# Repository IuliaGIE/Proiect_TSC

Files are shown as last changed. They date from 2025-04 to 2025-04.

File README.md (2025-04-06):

# DeskAssistant v15 – ESP32-C6 Smart E-Ink Device

## 🔧 Diagrama bloc

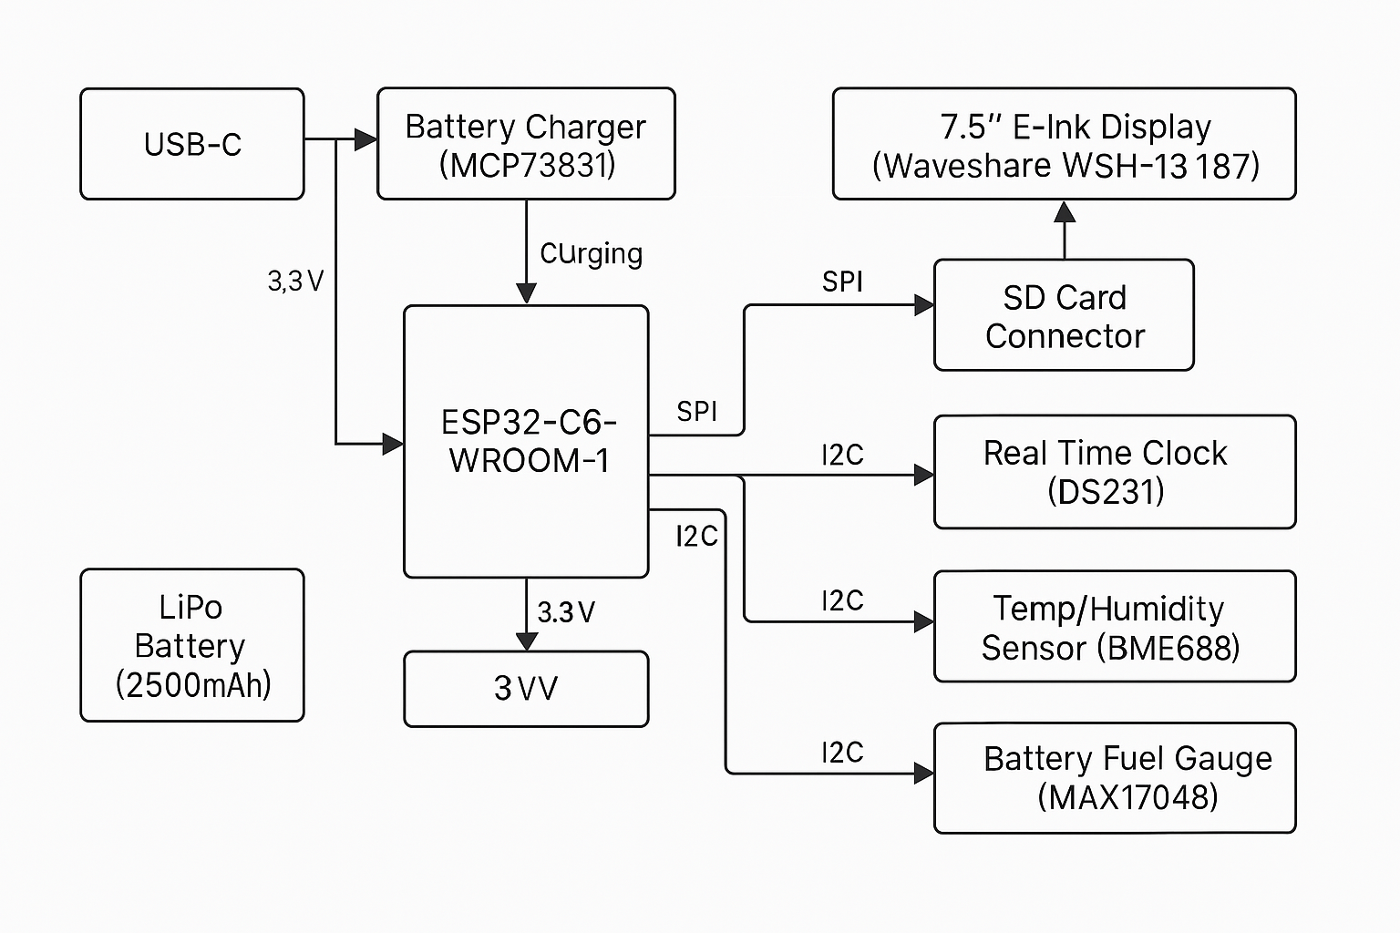
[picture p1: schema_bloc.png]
Diagrama Bloc


---

# Bill of Materials
| Componenta | Link | Datasheet
| --- | --- |---|
|ESP32_WROVER_BME680_BME680|https://www.snapeda.com/parts/BME680/Bosch/view-part/?welcome=home|https://www.snapeda.com/parts/BME680/Bosch%20Sensortec/datasheet/|
|ESP32_WROVER_EAGLE-LTSPICE_CC0402|https://componentsearchengine.com/Datasheets/2/CC0402MRX5R5BB106.pdf|https://componentsearchengine.com/part-view/CC0402MRX5R5BB106/YAGEO|
|ESP32_WROVER_SPARKFUN-DISCRETESEMI_MOSFET_PCH-DMG2305UX-7|https://componentsearchengine.com/part-view/DMG2305UX-7/Diodes%20Incorporated|https://www.diodes.com//assets/Datasheets/DMG2305UX.pdf|
|ESP32C6_VARISTORCN1812|https://www.mouser.co.uk/ProductDetail/EPCOS-TDK/B72520T0350K062?qs=dEfas%2FXlABIszF52uu7vrg%3D%3D|https://www.tdk-electronics.tdk.com/inf/75/db/CTVS_14/Surge_protection_series.pdf|
|FH34SRJ-24S-0.5SH_99_|https://componentsearchengine.com/part-view/XC6220A331MR-G/Torex|https://product.torexsemi.com/system/files/series/xc6220.pdf|
|MAX17048G+T10|https://www.snapeda.com/parts/MAX17048G+T10/Analog+Devices/view-part/?ref=eda|https://www.snapeda.com/parts/MAX17048G+T10/Analog%20Devices/datasheet/|
|MBR0530|https://ro.mouser.com/ProductDetail/KYOCERA-AVX/SD0805S020S1R0?qs=jCA%252BPfw4LHbpkAoSnwrdjw%3D%3D|https://ro.mouser.com/datasheet/2/40/schottky-3165252.pdf|
|PGB1010603MR|https://www.snapeda.com/parts/PGB1010603MR/Littelfuse/view-part/?ref=eda|https://www.snapeda.com/parts/PGB1010603MR/Littelfuse%20Inc./datasheet/|
|RCL_CPOL-EUCT3528|https://ro.mouser.com/ProductDetail/Vishay-Sprague/TR3B106K025C1300?qs=jCGqFXxTmLdffnuDkXzk1g%3D%3D|https://www.vishay.com/docs/40080/tr3.pdf|
|SAMACSYS_PARTS_USB4110-GF-A|https://componentsearchengine.com/part-view/USB4110-GF-A/GCT%20(GLOBAL%20CONNECTOR%20TECHNOLOGY)|https://gct.co/files/drawings/usb4110.pdf|
|SI1308EDL-T1-GE3|https://componentsearchengine.com/part-view/SI1308EDL-T1-GE3/Vishay|https://componentsearchengine.com/Datasheets/1/SI1308EDL-T1-GE3.pdf|
|SJ|https://grabcad.com/library/solder-jumpers-1||
|USBLC6-2SC6Y|https://www.snapeda.com/parts/USBLC6-2SC6Y/STMicroelectronics/view-part/?ref=eda|https://www.snapeda.com/parts/USBLC6-2SC6Y/STMicroelectronics/datasheet/|
|W25Q512JVEIQ|https://www.snapeda.com/parts/W25Q512JVEIQ/Winbond+Electronics/view-part/?ref=eda|https://www.snapeda.com/parts/W25Q512JVEIQ/Winbond%20Electronics/datasheet/|
|XC6220A331MR-G|https://componentsearchengine.com/part-view/XC6220A331MR-G/Torex|https://product.torexsemi.com/system/files/series/xc6220.pdf|
| ESP32_WROVER_EAGLE-LTSPICE_RR0402  | https://www.snapeda.com/parts/RC0402FR-07226RL/Yageo/view-part/ |https://www.snapeda.com/parts/RC0402FR-07226RL/Yageo/datasheet/
| QWIIC_CONNECTORJS-1MM | https://www.snapeda.com/parts/PRT-14417/SparkFun/view-part/ |https://www.snapeda.com/parts/PRT-14417/SparkFun%20Electronics/datasheet/
|BUTTON_CUSYOMV1|https://industry.panasonic.com/global/en/downloads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|https://industry.panasonic.com/global/en/downloads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
|ESP32_WROVER_EAGLE-LTSPICE_CC0402|https://componentsearchengine.com/part-view/CC0402MRX5R5BB106/YAGEO|https://componentsearchengine.com/Datasheets/2/CC0402MRX5R5BB106.pdf
|CPH3225A|https://www.snapeda.com/parts/CPH3225A/Seiko+Instruments/view-part/?ref=eda|https://www.snapeda.com/parts/CPH3225A/Seiko%20Instruments/datasheet/|
|ADAFRUIT_LEDCHIP-LED0603|https://www.snapeda.com/parts/KP-1608SURCK/Kingbright/view-part/?ref=search&t=LED%200603|https://www.snapeda.com/parts/KP-1608SURCK/Kingbright/datasheet/
|112A-TAAR-R03_ATTEND|https://store.comet.bg/en/Catalogue/Product/43497/|https://store.comet.bg/en/Catalogue/Product/43497/|
|744043680IND_4828-WE-TPC_WRE|https://www.digikey.sg/en/models/1638515|https://www.we-online.com/components/products/datasheet/744043680.pdf
|BD5229G-TR|https://componentsearchengine.com/part-view/BD5229G-TR/ROHM%20Semiconductor|https://datasheet.datasheetarchive.com/originals/distributors/Datasheets_SAMA/f2b9741ef86007909f138d561a359946.pdf|
|CPH3225A|https://www.snapeda.com/parts/CPH3225A/Seiko+Instruments/view-part/?ref=eda|https://www.snapeda.com/parts/CPH3225A/Seiko%20Instruments/datasheet/|
|DS3231SN|https://www.snapeda.com/parts/DS3231SN%23/Analog+Devices/view-part/?ref=eda|https://www.snapeda.com/parts/DS3231SN%23/Analog%20Devices/datasheet/|
|ESP32-C6-WROOM-1-N8|https://www.snapeda.com/parts/ESP32-C6-WROOM-1-N8/Espressif+Systems/view-part/?ref=eda|https://www.snapeda.com/parts/ESP32-C6-WROOM-1-N8/Espressif%20Systems/datasheet/
|MCP73831|https://www.digikey.com/en/models/1874108|https://ww1.microchip.com/downloads/aemDocuments/documents/APID/ProductDocuments/DataSheets/MCP73831-Family-Data-Sheet-DS20001984H.pdf|

---

## 🧠 Funcționalitate Hardware

DeskAssistant v15 este un dispozitiv portabil cu ecran E-Ink, destinat afișării de informații de mediu, oră și nivel baterie. Este alimentat fie prin USB-C, fie dintr-o baterie LiPo de 2500 mAh.

### Flux de alimentare:
- Portul USB-C oferă 5V către MCP73831, care încarcă bateria LiPo.
- Tensiunea de 3.7V de la baterie este convertită de un LDO în 3.3V, alimentând toate componentele.
- Monitorizarea bateriei este realizată cu MAX17048.

### Senzori și afișaj:
- Temperatura, umiditatea, presiunea și compușii volatili (VOC) sunt măsurați cu senzorul BME688 prin magistrala I2C.
- RTC-ul DS3231 furnizează ora exactă, tot prin I2C.
- Afișajul E-Ink de 7.5 inch este conectat prin SPI și oferă un consum redus de energie.
- Datele pot fi salvate pe un card microSD (SPI).
- Trei butoane conectate pe GPIO sunt utilizate pentru controlul interfeței.

### Calcul estimativ consum:
- ESP32-C6: ~20mA în idle, ~200mA în Wi-Fi TX
- E-Ink: consum doar în actualizare (~26mA)
- BME688: ~2.1mA în mod activ
- RTC: ~1.5μA
- MAX17048: ~50μA
- Autonomie estimată: ~30-40 ore în regim normal, cu Wi-Fi ocazional

---

## 📌 Maparea pinilor ESP32-C6

| Componentă | Pin ESP32-C6 | Interfață | Motivare |
|---|---|---|---|
| E-Ink Display | GPIO4 (MOSI), GPIO5 (MISO), GPIO6 (SCK), GPIO7 (CS), GPIO8 (DC), GPIO9 (RST), GPIO10 (BUSY) | SPI | Control complet al ecranului |
| SD Card | GPIO11 (CS2) | SPI (partajat) | Acces la stocare externă |
| BME688 | GPIO18 (SDA), GPIO19 (SCL) | I2C | Măsurători ambientale |
| MAX17048 | GPIO18 (SDA), GPIO19 (SCL) | I2C | Nivel baterie |
| DS3231 RTC | GPIO18 (SDA), GPIO19 (SCL) | I2C | Ceas exact |
| Butoane | GPIO21, GPIO22, GPIO23 | GPIO IN | Control manual |
| USB-C | GPIO20 (USB D+), GPIO21 (USB D-) | USB-Serial | Flash & debug |
| LED status | GPIO2 | GPIO OUT | Indicație vizuală |

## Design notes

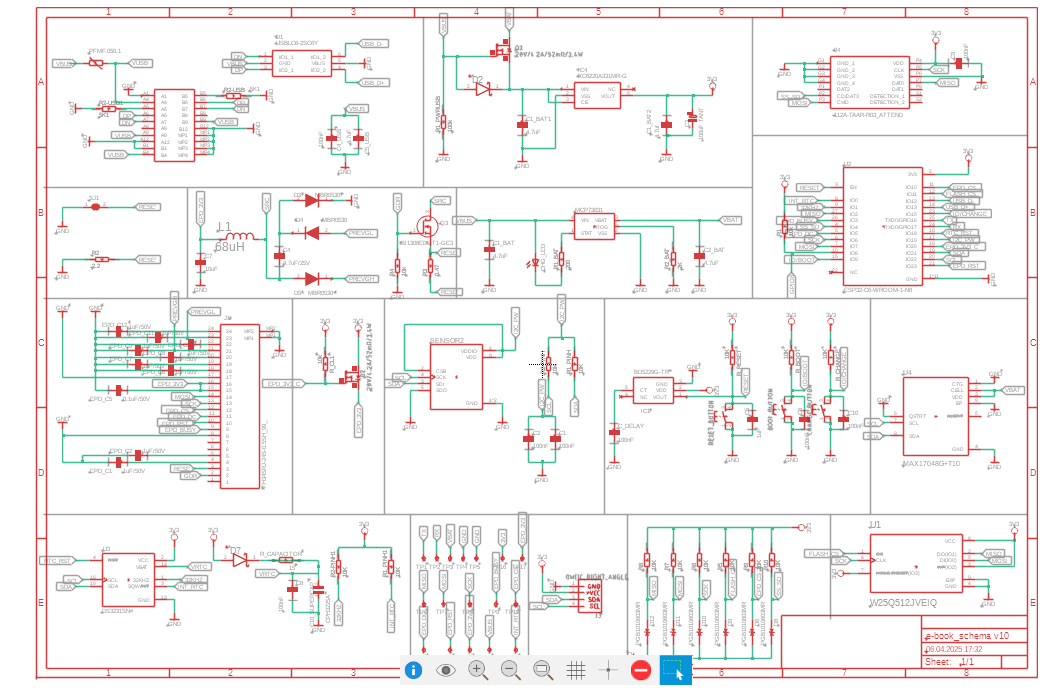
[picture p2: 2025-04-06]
Images/schema.png

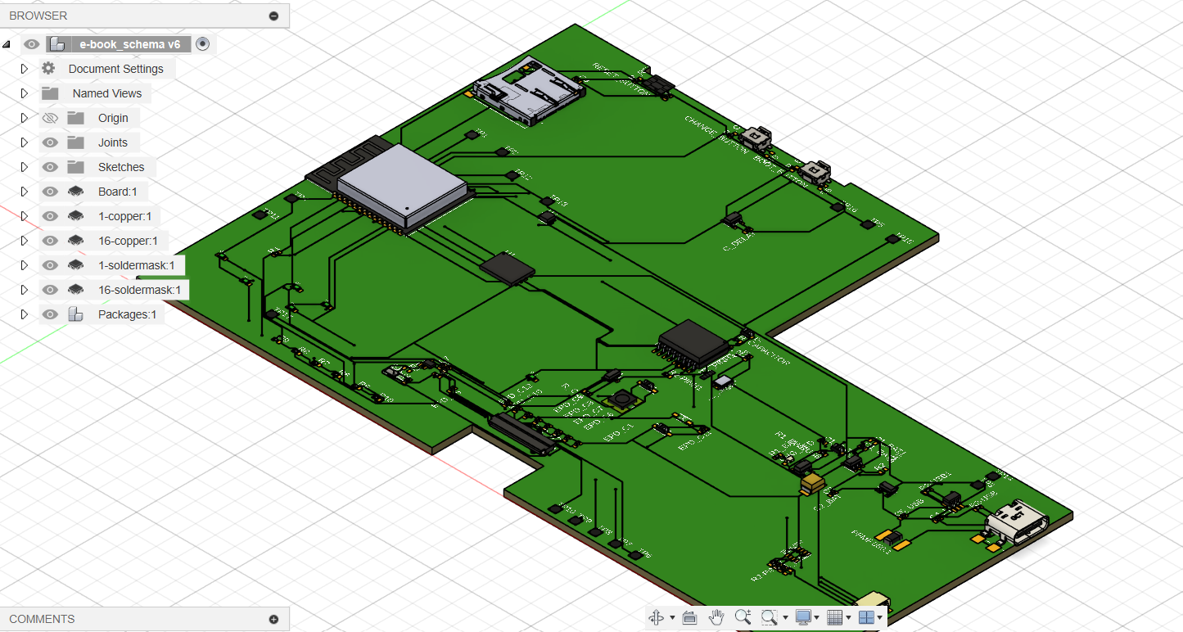
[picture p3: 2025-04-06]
Images/placuta.png

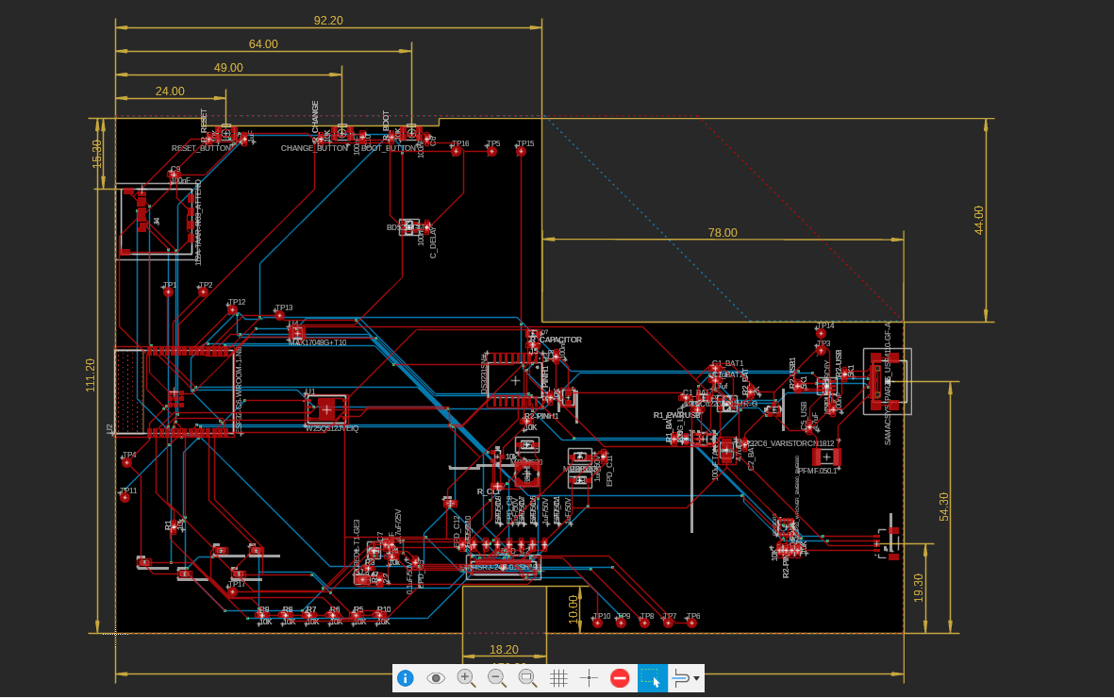
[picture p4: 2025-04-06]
Images/pcb.png

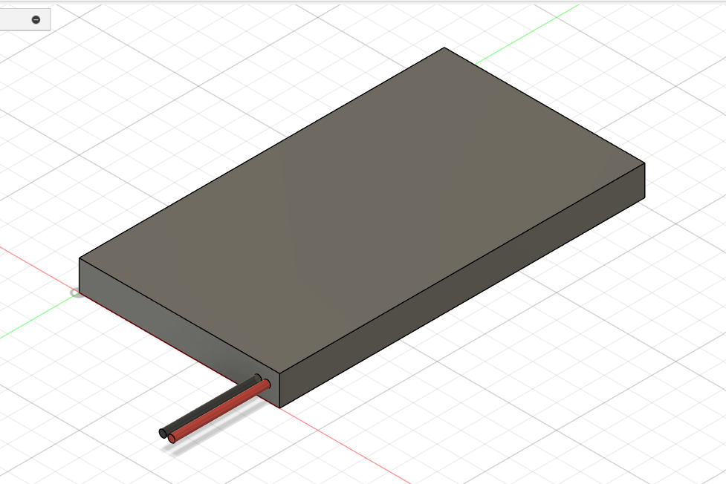
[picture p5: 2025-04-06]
Images/baterie.png

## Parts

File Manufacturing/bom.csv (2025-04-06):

Qty | Value | Device | Package | Parts | Description | ARROW_PART_NUMBER | ARROW_PRICE-STOCK | AVAILABILITY | CENTROID_NOT_SPECIFIED | CHECK_PRICES | COPYRIGHT | DATASHEET | DESCRIPTION | DIGIKEY_DESCRIPTION | DIGIKEY_PART_NUMBER | HEIGHT | LEAD_FREE | MANUFACTURER_NAME | MANUFACTURER_PART_NUMBER | MF | MFR_NAME | MOUSER_PART_NUMBER | MOUSER_PRICE-STOCK | MOUSER_TESTING_PART_NUMBER | MOUSER_TESTING_PRICE-STOCK | MP | MPN | PACKAGE | POPULARITY | PREFIX | PRICE | PROD_ID | PURCHASE-URL | ROHS | SNAPEDA_LINK | SPICEMODEL | SPICEPREFIX | TEMPERATURE_RANGE_HIGH | TEMPERATURE_RANGE_LOW | TP_SIGNAL_NAME | VALUE
1 |  | ADAFRUIT_LEDCHIP-LED0603 | ADAFRUIT_CHIP-LED0603 | CHG_LED | LED
1 |  | SJ | SJ | SJ1 | SMD solder JUMPER |  |  |  |  |  |  |  |  |  |  |  |  |  |  |  |  |  |  |  |  |  |  |  | 3
1 | 0.1uF/50V | EAGLE-LTSPICE_CC0402 | EAGLE-LTSPICE_C0402 | EPD_C5 | CAPACITOR, European symbol |  |  |  |  |  |  |  |  |  |  |  |  |  |  |  |  |  |  |  |  |  |  |  |  |  |  |  |  |  |  | NONE | C
1 | 0.47 | ESP32_WROVER_EAGLE-LTSPICE_RR0402 | ESP32_WROVER_EAGLE-LTSPICE_R0402 | R3 | RESISTOR, European symbol |  |  |  |  |  |  |  |  |  |  |  |  |  |  |  |  |  |  |  |  |  |  |  |  |  |  |  |  |  |  | NONE | R
1 | 100k | ESP32_WROVER_EAGLE-LTSPICE_RR0402 | ESP32_WROVER_EAGLE-LTSPICE_R0402 | R1_PWRUSB | RESISTOR, European symbol |  |  |  |  |  |  |  |  |  |  |  |  |  |  |  |  |  |  |  |  |  |  |  |  |  |  |  |  |  |  | NONE | R
8 | 100nF | EAGLE-LTSPICE_CC0402 | EAGLE-LTSPICE_C0402 | C1, C2, C4_USB, C6, C8, C9, C10, C_DELAY | CAPACITOR, European symbol |  |  |  |  |  |  |  |  |  |  |  |  |  |  |  |  |  |  |  |  |  |  |  |  |  |  |  |  |  |  | NONE | C
1 | 100uF TANT | RCL_CPOL-EUCT3528 | RCL_CT3528 | C3 | POLARIZED CAPACITOR, European symbol |  |  |  |  |  |  |  |  |  |  |  |  |  |  |  |  |  |  |  |  |  |  |  | 0 |  |  |  |  |  |  |  | C
13 | 10K | ESP32_WROVER_EAGLE-LTSPICE_RR0402 | ESP32_WROVER_EAGLE-LTSPICE_R0402 | R1_PINH, R1_PINH1, R2-PINH, R2-PINH1, R5, R6, R7, R8, R9, R10, R_BOOT, R_CHANGE, R_RESET | RESISTOR, European symbol |  |  |  |  |  |  |  |  |  |  |  |  |  |  |  |  |  |  |  |  |  |  |  |  |  |  |  |  |  |  | NONE | R
3 | 10k | ESP32_WROVER_EAGLE-LTSPICE_RR0402 | ESP32_WROVER_EAGLE-LTSPICE_R0402 | R1, R4, R_CL1 | RESISTOR, European symbol |  |  |  |  |  |  |  |  |  |  |  |  |  |  |  |  |  |  |  |  |  |  |  |  |  |  |  |  |  |  | NONE | R
1 | 10uF | EAGLE-LTSPICE_CC0402 | EAGLE-LTSPICE_C0402 | C7 | CAPACITOR, European symbol |  |  |  |  |  |  |  |  |  |  |  |  |  |  |  |  |  |  |  |  |  |  |  |  |  |  |  |  |  |  | NONE | C
1 | 112A-TAAR-R03_ATTEND | 112A-TAAR-R03_ATTEND | 112ATAARR03ATTEND | J4 | Micro SD Card Socket, Push-Push Type, Top Mount, SMT, H=1.83mm, 10u |  |  |  |  |  |  |  | Micro SD Card Socket | Push-Push Type | Top Mount | SMT | H=1.83mm | 10u |  |  | 1.9mm |  | ATTEND | 112A-TAAR-R03 ATTEND
1 | 15 | ESP32_WROVER_EAGLE-LTSPICE_RR0402 | ESP32_WROVER_EAGLE-LTSPICE_R0402 | R_CAPACITOR | RESISTOR, European symbol |  |  |  |  |  |  |  |  |  |  |  |  |  |  |  |  |  |  |  |  |  |  |  |  |  |  |  |  |  |  | NONE | R
1 | 1uF | EAGLE-LTSPICE_CC0402 | EAGLE-LTSPICE_C0402 | C5 | CAPACITOR, European symbol |  |  |  |  |  |  |  |  |  |  |  |  |  |  |  |  |  |  |  |  |  |  |  |  |  |  |  |  |  |  | NONE | C
9 | 1uF/50V | EAGLE-LTSPICE_CC0402 | EAGLE-LTSPICE_C0402 | EPD_C1, EPD_C2, EPD_C6, EPD_C7, EPD_C8, EPD_C9, EPD_C10, EPD_C11, EPD_C12 | CAPACITOR, European symbol |  |  |  |  |  |  |  |  |  |  |  |  |  |  |  |  |  |  |  |  |  |  |  |  |  |  |  |  |  |  | NONE | C
1 | 2.2 | ESP32_WROVER_EAGLE-LTSPICE_RR0402 | ESP32_WROVER_EAGLE-LTSPICE_R0402 | R2 | RESISTOR, European symbol |  |  |  |  |  |  |  |  |  |  |  |  |  |  |  |  |  |  |  |  |  |  |  |  |  |  |  |  |  |  | NONE | R
1 | 200 | ESP32_WROVER_EAGLE-LTSPICE_RR0402 | ESP32_WROVER_EAGLE-LTSPICE_R0402 | R1_BAT | RESISTOR, European symbol |  |  |  |  |  |  |  |  |  |  |  |  |  |  |  |  |  |  |  |  |  |  |  |  |  |  |  |  |  |  | NONE | R
2 | 20V/4.2A/52mO/1.4W | ESP32_WROVER_SPARKFUN-DISCRETESEMI_MOSFET_PCH-DMG2305UX-7 | ESP32_WROVER_SPARKFUN-DISCRETESEMI_SOT23-3 | Q1, Q2 | P-channel MOSFETs |  |  |  |  |  |  |  |  |  |  |  |  |  |  |  |  |  |  |  |  |  |  |  |  |  |  | TRAN-14388 |  |  |  |  |  |  |  |  | 20V/4.2A/52mO/1.4W
1 | 2K | ESP32_WROVER_EAGLE-LTSPICE_RR0402 | ESP32_WROVER_EAGLE-LTSPICE_R0402 | R2_BAT | RESISTOR, European symbol |  |  |  |  |  |  |  |  |  |  |  |  |  |  |  |  |  |  |  |  |  |  |  |  |  |  |  |  |  |  | NONE | R
4 | 4.7uF | EAGLE-LTSPICE_CC0402 | EAGLE-LTSPICE_C0402 | C1_BAT, C1_BAT1, C2_BAT, C5_USB | CAPACITOR, European symbol |  |  |  |  |  |  |  |  |  |  |  |  |  |  |  |  |  |  |  |  |  |  |  |  |  |  |  |  |  |  | NONE | C
1 | 4.7uF/25V | EAGLE-LTSPICE_CC0402 | EAGLE-LTSPICE_C0402 | C4 | CAPACITOR, European symbol |  |  |  |  |  |  |  |  |  |  |  |  |  |  |  |  |  |  |  |  |  |  |  |  |  |  |  |  |  |  | NONE | C
1 | 4.7uf | EAGLE-LTSPICE_CC0402 | EAGLE-LTSPICE_C0402 | C1_BAT2 | CAPACITOR, European symbol |  |  |  |  |  |  |  |  |  |  |  |  |  |  |  |  |  |  |  |  |  |  |  |  |  |  |  |  |  |  | NONE | C
2 | 5K1 | ESP32_WROVER_EAGLE-LTSPICE_RR0402 | ESP32_WROVER_EAGLE-LTSPICE_R0402 | R2-USB, R2-USB1 | RESISTOR, European symbol |  |  |  |  |  |  |  |  |  |  |  |  |  |  |  |  |  |  |  |  |  |  |  |  |  |  |  |  |  |  | NONE | R
1 | 68uH | 744043680IND_4828-WE-TPC_WRE | IND_4828-WE-TPC_WRE | L1 |  |  |  |  |  |  | Copyright (C) 2024 Ultra Librarian. All rights reserved. |  |  |  |  |  |  |  | 744043680 |  | Wurth Electronics
1 | BD5229G-TR | BD5229G-TR | SOT95P280X125-5N | IC1 | Voltage Detector with Adjustable Delay Time: CMOS processes are utilized to develop high precision, low current consumption CMOS reset ICs that allow arbitrary setting of the delay time. The extensive lineup includes both Nch Open Drain and CMOS output types in a wide range of detection voltages (from 2.3V to 6.0V, in 0.1V steps), enabling selection of the ideal solution based on customer requirements. In addition, the entire series is of course both lead-free and RoHS-compliant. |  |  |  |  |  |  |  | Voltage Detector with Adjustable Delay Time: CMOS processes are utilized to develop high precision | low current consumption CMOS reset ICs that allow arbitrary setting of the delay time. The extensive lineup includes both Nch Open Drain and CMOS output types in a wide range of detection voltages (from 2.3V to 6.0V | in 0.1V steps) | enabling selection of the ideal solution based on customer requirements. In addition | the entire series is of course both lead-free and RoHS-compliant. |  |  | 1.25mm |  | ROHM Semiconductor | BD5229G-TR |  |  | 755-BD5229G-TR | https://www.mouser.co.uk/ProductDetail/ROHM-Semiconductor/BD5229G-TR?qs=4kLU8WoGk0vvnhrrYwdszw%3D%3D
3 | BUTTON_CUSYOMV1 | BUTTON_CUSYOMV1 | MYBUTTON | BOOT_BUTTON, CHANGE_BUTTON, RESET_BUTTON
1 | CPH3225A | CPH3225A | CAPCP3225X100N | C10_SUPERCAP | Cap 0.011F 3.3V 1210 Flat Check availability |  |  | Not in stock |  | https://www.snapeda.com/parts/CPH3225A/Seiko+Instruments/view-part/?ref=eda |  |  | 11 mF (EDLC) Supercapacitor 3.3 V 1210 (3225 Metric) - - |  |  |  |  |  |  | Seiko Instruments |  |  |  |  |  | CPH3225A |  | 1210 Seiko |  |  | None |  | https://www.snapeda.com/api/url_track_click_mouser/?unipart_id=562593&manufacturer=Seiko Instruments&part_name=CPH3225A&search_term=None |  | https://www.snapeda.com/parts/CPH3225A/Seiko+Instruments/view-part/?ref=snap
1 | DS3231SN# | DS3231SN# | SOIC127P1032X265-16N | U3 | Real Time Clock Serial 16-Pin SOIC W T/R Check availability |  |  | In Stock |  | https://www.snapeda.com/parts/DS3231SN%23/Analog+Devices/view-part/?ref=eda |  |  | Extremely Accurate I²C-Integrated RTC/TCXO/Crystal |  |  |  |  |  |  | Analog Devices |  |  |  |  |  | DS3231SN# |  | SOIC-16 Maxim |  |  | None |  | https://www.snapeda.com/api/url_track_click_mouser/?unipart_id=99048&manufacturer=Analog Devices&part_name=DS3231SN#&search_term=None |  | https://www.snapeda.com/parts/DS3231SN%23/Analog+Devices/view-part/?ref=snap
1 | ESP32-C6-WROOM-1-N8 | ESP32-C6-WROOM-1-N8 | XCVR_ESP32-C6-WROOM-1-N8 | U2 | Check availability |  |  | In Stock |  | https://www.snapeda.com/parts/ESP32-C6-WROOM-1-N8/Espressif+Systems/view-part/?ref=eda |  |  | Multiprotocol Modules ESP32-C6 module | Wi-Fi 6 in 2.4 GHz band | Bluetooth 5 | Zigbee 3.0 and Thread. ESP34-WROOM Compatible - ENGINEERING SAMPLE |  |  |  |  |  |  | Espressif Systems |  |  |  |  |  | ESP32-C6-WROOM-1-N8 |  | None |  |  | None |  |  |  | https://www.snapeda.com/parts/ESP32-C6-WROOM-1-N8/Espressif+Systems/view-part/?ref=snap
1 | ESP32C6_VARISTORCN1812 | ESP32C6_VARISTORCN1812 | ESP32C6_VARISTOR_CT/CN1812 | PFMF.050.1 | VARISTOR |  |  |  |  |  |  |  |  |  |  |  |  |  |  |  |  |  |  |  |  |  |  |  | 0
2 | ESP32_WROVER_AVX---SD0805S020S1R0_AVX_SD0805S020S1R0_0_0AVX_SD0805S020S1R0_0_0 | ESP32_WROVER_AVX---SD0805S020S1R0_AVX_SD0805S020S1R0_0_0AVX_SD0805S020S1R0_0_0 | ESP32_WROVER_AVX---SD0805S020S1R0_AVX_SD0805S020S1R0_0 | D2, D7 | Schottky Barrier Rectifier Diode |  |  |  | No |  |  | http://datasheets.avx.com/schottky.pdf |  | DIODE SCHOTTKY 20V 1A 0805 | 478-7800-1-ND |  | yes |  |  | AVX |  | 581-SD0805S020S1R0 |  |  |  |  |  | 0805 (2012 metric) |  | D |  |  |  | yes |  |  |  | +125°C | -55°C
1 | ESP32_WROVER_BME680_BME680 | ESP32_WROVER_BME680_BME680 | ESP32_WROVER_BME680_PSON80P300X300X100-8N | SENSOR2 | Integrated Environmental Unit |  |  | Unavailable |  |  |  |  | Integrated Environmental Unit |  |  |  |  |  |  | Bosch Sensortec |  |  |  |  |  | BME680 |  | LGA-8 Bosch Tools |  |  | None
1 | ESP32_WROVER_SPARKFUN-IC-POWER_MCP73831 | ESP32_WROVER_SPARKFUN-IC-POWER_MCP73831 | ESP32_WROVER_SPARKFUN-IC-POWER_SOT23-5 | MCP73831 | MCP73831T Li-Ion, Li-Pol Controller |  |  |  |  |  |  |  |  |  |  |  |  |  |  |  |  |  |  |  |  |  |  |  |  |  |  | IC-09995
1 | FH34SRJ-24S-0.5SH_99_ | FH34SRJ-24S-0.5SH_99_ | FH34SRJ24S05SH99 | J1 | (0.50mm) Surface Mount, Right Angle |  |  |  |  |  |  |  | 24 Position FFC | FPC Connector Contacts | (0.50mm) Surface Mount | Right Angle |  |  | 1.1mm |  | Hirose | FH34SRJ-24S-0.5SH(99) |  |  | 798-FH34SRJ24S05SH99 | https://www.mouser.co.uk/ProductDetail/Hirose-Connector/FH34SRJ-24S-0.5SH99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
1 | MAX17048G+T10 | MAX17048G+T10 | SON50P200X200X80-9N | U4 | Check availability |  |  | In Stock |  | https://www.snapeda.com/parts/MAX17048G+T10/Analog+Devices/view-part/?ref=eda |  |  | 3µA 1-Cell/2-Cell Fuel Gauge with ModelGauge |  |  |  |  |  |  | Analog Devices |  |  |  |  |  | MAX17048G+T10 |  | TDFN-8 Maxim |  |  | None |  | https://www.snapeda.com/api/url_track_click_mouser/?unipart_id=329239&manufacturer=Analog Devices&part_name=MAX17048G+T10&search_term=None |  | https://www.snapeda.com/parts/MAX17048G+T10/Analog+Devices/view-part/?ref=snap
3 | MBR0530 | MBR0530 | SOD3716X135N | D3, D4, D5 | ON SEMICONDUCTOR - MBR0530 - DIODE, SCHOTTKY, 0.5A, 30V, SOD-123 |  |  | In Stock |  | https://www.snapeda.com/parts/MBR0530/Onsemi/view-part/?ref=eda |  |  | Diode Schottky 30 V 500mA Surface Mount SOD-123 |  |  |  |  |  |  | ON Semiconductor |  |  |  |  |  | MBR0530 |  | SOD-123-2 ON Semiconductor |  |  | None |  | https://www.snapeda.com/api/url_track_click_mouser/?unipart_id=179458&manufacturer=ON Semiconductor&part_name=MBR0530&search_term=None |  | https://www.snapeda.com/parts/MBR0530/Onsemi/view-part/?ref=snap
6 | PGB1010603MR | PGB1010603MR | DIOC1608X36N | D6, D8, D9, D10, D11, D12 | Check availability |  |  | In Stock |  | https://www.snapeda.com/parts/PGB1010603MR/Littelfuse/view-part/?ref=eda |  |  | 150V (Typ) Clamp - Ipp Tvs Diode Surface Mount 0603 (1608 Metric) |  |  |  |  |  |  | Littelfuse Inc. |  |  |  |  |  | PGB1010603MR |  | 0603 Littelfuse Inc. |  |  | None |  | https://www.snapeda.com/api/url_track_click_mouser/?unipart_id=5659453&manufacturer=Littelfuse Inc.&part_name=PGB1010603MR&search_term=None |  | https://www.snapeda.com/parts/PGB1010603MR/Littelfuse/view-part/?ref=snap
1 | QWIIC_RIGHT_ANGLE | QWIIC_CONNECTORJS-1MM | JST04_1MM_RA | J3 | SparkFun I2C Standard Qwiic Connector |  |  |  |  |  |  |  |  |  |  |  |  |  |  |  |  |  |  |  |  |  |  |  |  |  |  | CONN-13694 |  |  |  |  |  |  |  |  | QWIIC_RIGHT_ANGLE
1 | SAMACSYS_PARTS_USB4110-GF-A | SAMACSYS_PARTS_USB4110-GF-A | SAMACSYS_PARTS_USB4110GFA | J2 | CONN USB 2.0 TYPE-C R/A SMT |  |  |  |  |  |  |  | CONN USB 2.0 TYPE-C R/A SMT |  |  | 3.26mm |  | GCT (GLOBAL CONNECTOR TECHNOLOGY) | USB4110-GF-A |  |  | 640-USB4110-GF-A | https://www.mouser.co.uk/ProductDetail/GCT/USB4110-GF-A?qs=KUoIvG%2F9IlYiZvIXQjyJeA%3D%3D
1 | SI1308EDL-T1-GE3 | SI1308EDL-T1-GE3 | SOT65P210X110-3N | Q3 | MOSFET N-Ch 30V 1.5A TrenchFET SC70 Vishay Si1308EDL-T1-GE3 N-channel MOSFET Transistor, 1.5 A, 30 V, 3-Pin SC-70 |  |  | In Stock |  | https://www.snapeda.com/parts/SI1308EDL-T1-GE3/Vishay+Siliconix/view-part/?ref=eda |  |  | Si1308EDL-T1-GE3 N-channel MOSFET Transistor | 1.5 A | 30 V | 3-Pin SC-70 | Siliconix / Vishay SI1308EDL-T1-GE3 |  |  |  |  |  |  | Vishay Siliconix |  |  |  |  |  | SI1308EDL-T1-GE3 |  | SOT-323 Vishay Semiconductor |  |  | None |  | https://www.snapeda.com/api/url_track_click_mouser/?unipart_id=274603&manufacturer=Vishay Siliconix&part_name=SI1308EDL-T1-GE3&search_term=None |  | https://www.snapeda.com/parts/SI1308EDL-T1-GE3/Vishay+Siliconix/view-part/?ref=snap
17 | TPTP20R | TPTP20R | TP20R | TP1, TP2, TP3, TP4, TP5, TP6, TP7, TP8, TP9, TP10, TP11, TP12, TP13, TP14, TP15, TP16, TP17 | Test pad |  |  |  |  |  |  |  |  |  |  |  |  |  |  |  |  |  |  |  |  |  |  |  | 2
1 | USBLC6-2SC6Y | USBLC6-2SC6Y | SOT95P280X145-6N | D1 | Low Cap. ESD Protection Auto SOT-23-6 STMicroelectronics USBLC6-2SC6Y, Dual Uni-Directional TVS Diode Array, 6-Pin SOT-23 |  |  | In Stock |  | https://www.snapeda.com/parts/USBLC6-2SC6Y/STMicroelectronics/view-part/?ref=eda |  |  | 17V Clamp 5A (8/20µs) Ipp Tvs Diode Surface Mount SOT-23-6 |  |  |  |  |  |  | STMicroelectronics |  |  |  |  |  | USBLC6-2SC6Y |  | SOT-23-6 STMicroelectronics |  |  | None |  |  |  | https://www.snapeda.com/parts/USBLC6-2SC6Y/STMicroelectronics/view-part/?ref=snap
1 | W25Q512JVEIQ | W25Q512JVEIQ | SON127P600X800X80-9N | U1 | Check availability |  |  | In Stock |  | https://www.snapeda.com/parts/W25Q512JVEIQ/Winbond+Electronics/view-part/?ref=eda |  |  | FLASH - NOR Memory IC 512Mb (64M x 8) SPI - Quad I/O 133 MHz 8-WSON (8x6) |  |  |  |  |  |  | Winbond Electronics |  |  |  |  |  | W25Q512JVEIQ |  | Package |  |  | None |  |  |  | https://www.snapeda.com/parts/W25Q512JVEIQ/Winbond+Electronics/view-part/?ref=snap
1 | XC6220A331MR-G | XC6220A331MR-G | SOT95P280X120-5N | IC4 | LDO Voltage Regulators |  |  |  |  |  |  |  | LDO Voltage Regulators |  |  | 1.2mm |  | Torex | XC6220A331MR-G |  |  | 865-XC6220A331MR-G | https://www.mouser.co.uk/ProductDetail/Torex-Semiconductor/XC6220A331MR-G?qs=AsjdqWjXhJ8ZSWznL1J0gg%3D%3D

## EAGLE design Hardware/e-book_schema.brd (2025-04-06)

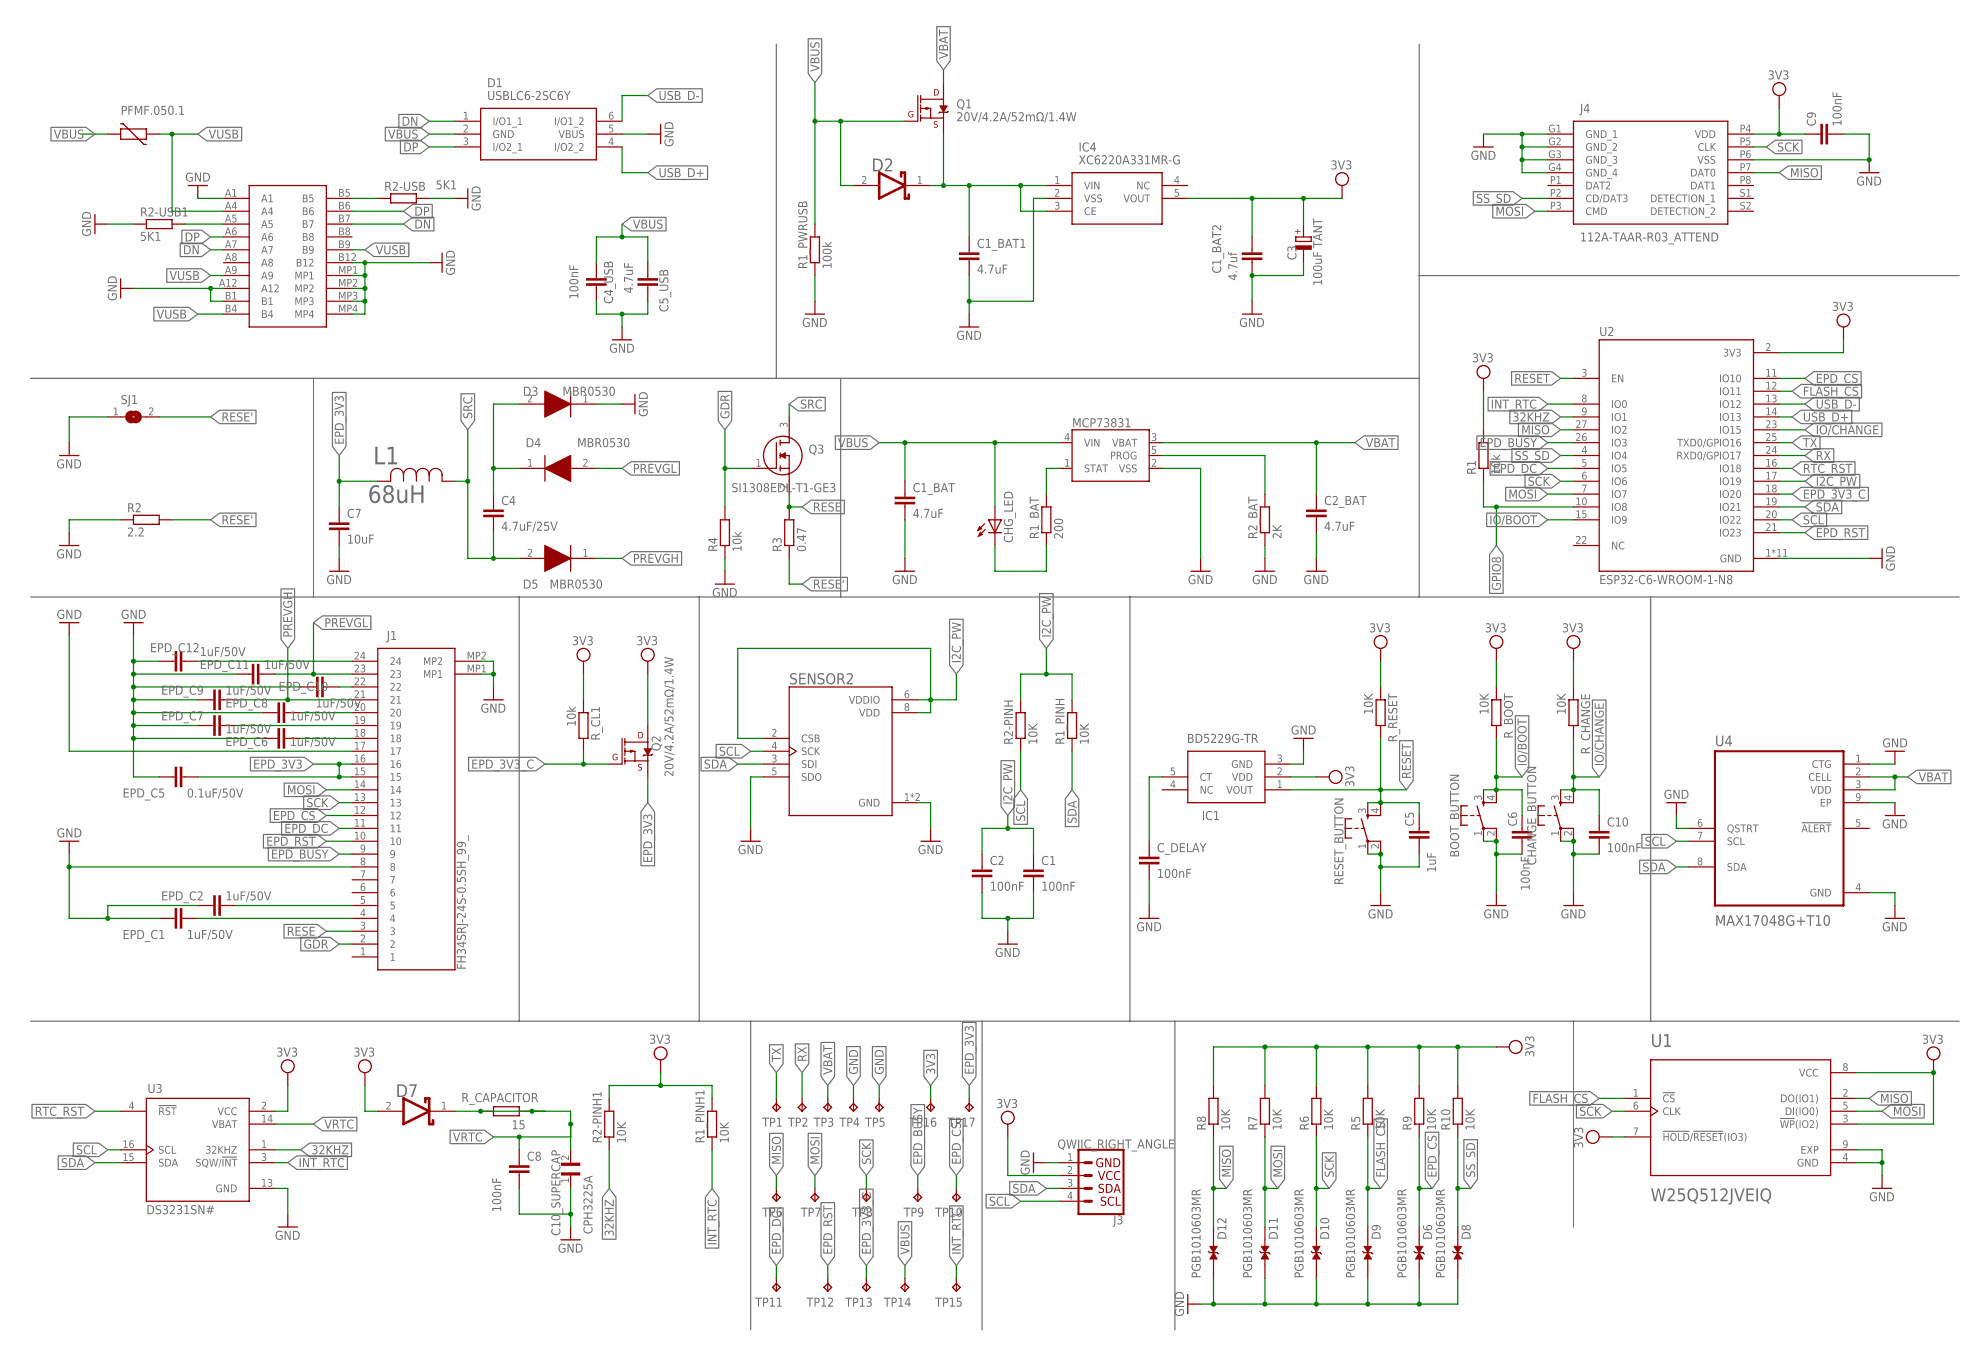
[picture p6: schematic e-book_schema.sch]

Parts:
BOOT_BUTTON: BUTTON_CUSYOMV1; MYBUTTON
C1, C2, C4_USB, C6, C8, C9, C10: 100nF; EAGLE-LTSPICE_C0402
C1_BAT, C1_BAT1, C2_BAT, C5_USB: 4.7uF; EAGLE-LTSPICE_C0402
C1_BAT2: 4.7uf; EAGLE-LTSPICE_C0402
C3: 100uF TANT; RCL_CT3528
C4: 4.7uF/25V; EAGLE-LTSPICE_C0402
C5: 1uF; EAGLE-LTSPICE_C0402
C7: 10uF; EAGLE-LTSPICE_C0402
C10_SUPERCAP: CPH3225A; CAPCP3225X100N
CHANGE_BUTTON: BUTTON_CUSYOMV1; MYBUTTON
CHG_LED: ADAFRUIT_LEDCHIP-LED0603; ADAFRUIT_CHIP-LED0603
C_DELAY: 100nF; EAGLE-LTSPICE_C0402
D1: USBLC6-2SC6Y; SOT95P280X145-6N
D2, D7: ESP32_WROVER_AVX---SD0805S020S1R0_AVX_SD0805S020S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; ESP32_WROVER_AVX---SD0805S020S1R0_AVX_SD0805S020S1R0_0
D3, D4, D5: MBR0530; SOD3716X135N
D6, D8, D9, D10, D11, D12: PGB1010603MR; DIOC1608X36N
EPD_C1, EPD_C2, EPD_C6, EPD_C7, EPD_C8, EPD_C9, EPD_C10, EPD_C11, EPD_C12: 1uF/50V; EAGLE-LTSPICE_C0402
EPD_C5: 0.1uF/50V; EAGLE-LTSPICE_C0402
IC1: BD5229G-TR; SOT95P280X125-5N
IC4: XC6220A331MR-G; SOT95P280X120-5N
J1: FH34SRJ-24S-0.5SH_99_; FH34SRJ24S05SH99
J2: SAMACSYS_PARTS_USB4110-GF-A; SAMACSYS_PARTS_USB4110GFA
J3: QWIIC_RIGHT_ANGLE; JST04_1MM_RA
J4: 112A-TAAR-R03_ATTEND; 112ATAARR03ATTEND
L1: 68uH; IND_4828-WE-TPC_WRE
MCP73831: ESP32_WROVER_SPARKFUN-IC-POWER_MCP73831; ESP32_WROVER_SPARKFUN-IC-POWER_SOT23-5
PFMF.050.1: ESP32C6_VARISTORCN1812; ESP32C6_VARISTOR_CT/CN1812
Q1, Q2: 20V/4.2A/52mΩ/1.4W; ESP32_WROVER_SPARKFUN-DISCRETESEMI_SOT23-3
Q3: SI1308EDL-T1-GE3; SOT65P210X110-3N
R1, R4: 10k; ESP32_WROVER_EAGLE-LTSPICE_R0402
R1_BAT: 200; ESP32_WROVER_EAGLE-LTSPICE_R0402
R1_PINH, R1_PINH1, R2-PINH, R2-PINH1, R5, R6, R7, R8, R9, R10: 10K; ESP32_WROVER_EAGLE-LTSPICE_R0402
R1_PWRUSB: 100k; ESP32_WROVER_EAGLE-LTSPICE_R0402
R2: 2.2; ESP32_WROVER_EAGLE-LTSPICE_R0402
R2-USB, R2-USB1: 5K1; ESP32_WROVER_EAGLE-LTSPICE_R0402
R2_BAT: 2K; ESP32_WROVER_EAGLE-LTSPICE_R0402
R3: 0.47; ESP32_WROVER_EAGLE-LTSPICE_R0402
RESET_BUTTON: BUTTON_CUSYOMV1; MYBUTTON
R_BOOT: 10K; ESP32_WROVER_EAGLE-LTSPICE_R0402
R_CAPACITOR: 15; ESP32_WROVER_EAGLE-LTSPICE_R0402
R_CHANGE: 10K; ESP32_WROVER_EAGLE-LTSPICE_R0402
R_CL1: 10k; ESP32_WROVER_EAGLE-LTSPICE_R0402
R_RESET: 10K; ESP32_WROVER_EAGLE-LTSPICE_R0402
SENSOR2: ESP32_WROVER_BME680_BME680; ESP32_WROVER_BME680_PSON80P300X300X100-8N
SJ1: SJ
TP1, TP2, TP3, TP4, TP5, TP6, TP7, TP8, TP9, TP10, TP11, TP12, TP13, TP14, TP15, TP16, TP17: TPTP20R; TP20R
U1: W25Q512JVEIQ; SON127P600X800X80-9N
U2: ESP32-C6-WROOM-1-N8; XCVR_ESP32-C6-WROOM-1-N8
U3: DS3231SN#; SOIC127P1032X265-16N
U4: MAX17048G+T10; SON50P200X200X80-9N

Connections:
3V3: C1_BAT2.1, C3.+, C9.1, D7.2 (ANODE), IC1.2 (VDD), IC4.5 (VOUT), J3.2, J4.P4 (VDD), Q2.3 (D), R1.2, R1_PINH1.2, R2-PINH1.2, R5.2, R6.2, R7.2, R8.2, R9.2, R10.2, R_BOOT.1, R_CHANGE.1, R_CL1.1, R_RESET.1, TP16.TP, U1.3 (!WP!(IO2)), U1.7 (!HOLD!/!RESET!(IO3)), U1.8 (VCC), U2.2 (3V3), U3.2 (VCC)
32KHZ: R2-PINH1.1, U2.9 (IO1), U3.1 (32KHZ)
DN: D1.1 (I/O1_1), J2.A7, J2.B7
DP: D1.3 (I/O2_1), J2.A6, J2.B6
EPD_3V3: C7.1, EPD_C5.1, J1.15, J1.16, L1.2, Q2.2 (S), TP17.TP
EPD_3V3_C: Q2.1 (G), R_CL1.2, TP13.TP, U2.18 (IO20)
EPD_BUSY: J1.9, TP9.TP, U2.26 (IO3)
EPD_CS: D6.2, J1.12, R9.1, TP10.TP, U2.11 (IO10)
EPD_DC: J1.11, TP11.TP, U2.5 (IO5)
EPD_RST: J1.10, TP12.TP, U2.21 (IO23)
FLASH_CS: D9.2, R5.1, U1.1 (!CS), U2.12 (IO11)
GDR: J1.2, Q3.1 (G), R4.2
GND: BOOT_BUTTON.1, BOOT_BUTTON.2, C1.2, C1_BAT.2, C1_BAT1.2, C1_BAT2.2, C2.2, C2_BAT.2, C3.-, C4_USB.2, C5.2, C5_USB.2, C6.2, C7.2, C8.2, C9.2, C10.2, C10_SUPERCAP.1, CHANGE_BUTTON.1, CHANGE_BUTTON.2, C_DELAY.2, D1.5 (VBUS), D3.1 (K), D6.1, D8.1, D9.1, D10.1, D11.1, D12.1, EPD_C1.2, EPD_C2.2, EPD_C5.2, EPD_C6.2, EPD_C7.2, EPD_C8.2, EPD_C9.2, EPD_C10.2, EPD_C11.2, EPD_C12.2, IC1.3 (GND), IC4.2 (VSS), J1.8, J1.17, J1.MP1, J1.MP2, J2.A1, J2.A12, J2.B1, J2.B12, J2.MP1, J2.MP2, J2.MP3, J2.MP4, J3.1, J4.G1 (GND_1), J4.G2 (GND_2), J4.G3 (GND_3), J4.G4 (GND_4), J4.P6 (VSS), MCP73831.2 (VSS), R1_PWRUSB.1, R2.1, R2-USB.2, R2-USB1.1, R2_BAT.1, R4.1, RESET_BUTTON.1, RESET_BUTTON.2, SENSOR2.1 (GND), SENSOR2.5 (SDO), SENSOR2.7 (GND), SJ1.1, TP4.TP, TP5.TP, U1.4 (GND), U1.9 (EXP), U2.1 (GND), U2.28 (GND), U2.29_1 (GND), U2.29_2 (GND), U2.29_3 (GND), U2.29_4 (GND), U2.29_5 (GND), U2.29_6 (GND), U2.29_7 (GND), U2.29_8 (GND), U2.29_9 (GND), U3.13 (GND), U4.1 (CTG), U4.4 (GND), U4.6 (QSTRT), U4.9 (EP)
GPIO8: R1.1, U2.10 (IO8)
I2C_PW: C1.1, C2.1, R1_PINH.2, R2-PINH.2, SENSOR2.2 (CSB), SENSOR2.6 (VDDIO), SENSOR2.8 (VDD), U2.17 (IO19)
INT_RTC: R1_PINH1.1, TP15.TP, U2.8 (IO0), U3.3 (SQW/!INT)
IO/BOOT: BOOT_BUTTON.3, BOOT_BUTTON.4, C6.1, R_BOOT.2, U2.15 (IO9)
IO/CHANGE: C10.1, CHANGE_BUTTON.3, CHANGE_BUTTON.4, R_CHANGE.2, U2.23 (IO15)
MISO: D12.2, J4.P7 (DAT0), R8.1, TP6.TP, U1.2 (DO(IO1)), U2.27 (IO2)
MOSI: D11.2, J1.14, J4.P3 (CMD), R7.1, TP7.TP, U1.5 (DI(IO0)), U2.7 (IO7)
unnamed: J2.A5, R2-USB1.2
unnamed: J2.B5, R2-USB.1
unnamed: C1_BAT1.1, D2.1 (CATHODE), IC4.1 (VIN), IC4.3 (CE), Q1.2 (S)
unnamed: EPD_C12.1, J1.24
unnamed: C4.1, D3.2 (A), D4.1 (K)
unnamed: CHG_LED.C, R1_BAT.1
unnamed: MCP73831.1 (STAT), R1_BAT.2
unnamed: MCP73831.5 (PROG), R2_BAT.2
unnamed: C_DELAY.1, IC1.5 (CT)
unnamed: EPD_C10.1, J1.22
unnamed: EPD_C8.1, J1.20
unnamed: EPD_C7.1, J1.19
unnamed: EPD_C6.1, J1.18
unnamed: EPD_C2.1, J1.5
unnamed: EPD_C1.1, J1.4
PREVGH: D5.1 (K), EPD_C9.1, J1.21
PREVGL: D4.2 (A), EPD_C11.1, J1.23
RESE: J1.3, Q3.2 (S), R3.2
RESE': R2.2, R3.1, SJ1.2
RESET: C5.1, IC1.1 (VOUT), RESET_BUTTON.3, RESET_BUTTON.4, R_RESET.2, U2.3 (EN)
RTC_RST: U2.16 (IO18), U3.4 (!RST)
RX: TP2.TP, U2.24 (RXD0/GPIO17)
SCK: D10.2, J1.13, J4.P5 (CLK), R6.1, TP8.TP, U1.6 (CLK), U2.6 (IO6)
SCL: J3.4, R2-PINH.1, SENSOR2.4 (SCK), U2.20 (IO22), U3.16 (SCL), U4.7 (SCL)
SDA: J3.3, R1_PINH.1, SENSOR2.3 (SDI), U2.19 (IO21), U3.15 (SDA), U4.8 (SDA)
SRC: C4.2, D5.2 (A), L1.1, Q3.3 (D)
SS_SD: D8.2, J4.P2 (CD/DAT3), R10.1, U2.4 (IO4)
TX: TP1.TP, U2.25 (TXD0/GPIO16)
USB_D+: D1.4 (I/O2_2), U2.14 (IO13)
USB_D-: D1.6 (I/O1_2), U2.13 (IO12)
VBAT: C2_BAT.1, MCP73831.3 (VBAT), Q1.3 (D), TP3.TP, U4.2 (CELL), U4.3 (VDD)
VBUS: C1_BAT.1, C4_USB.1, C5_USB.1, CHG_LED.A, D1.2 (GND), D2.2 (ANODE), MCP73831.4 (VIN), PFMF.050.1.2, Q1.1 (G), R1_PWRUSB.2, TP14.TP
VRTC: C8.1, C10_SUPERCAP.2, D7.1 (CATHODE), R_CAPACITOR.1, R_CAPACITOR.2, U3.14 (VBAT)
VUSB: J2.A4, J2.A9, J2.B4, J2.B9, PFMF.050.1.1

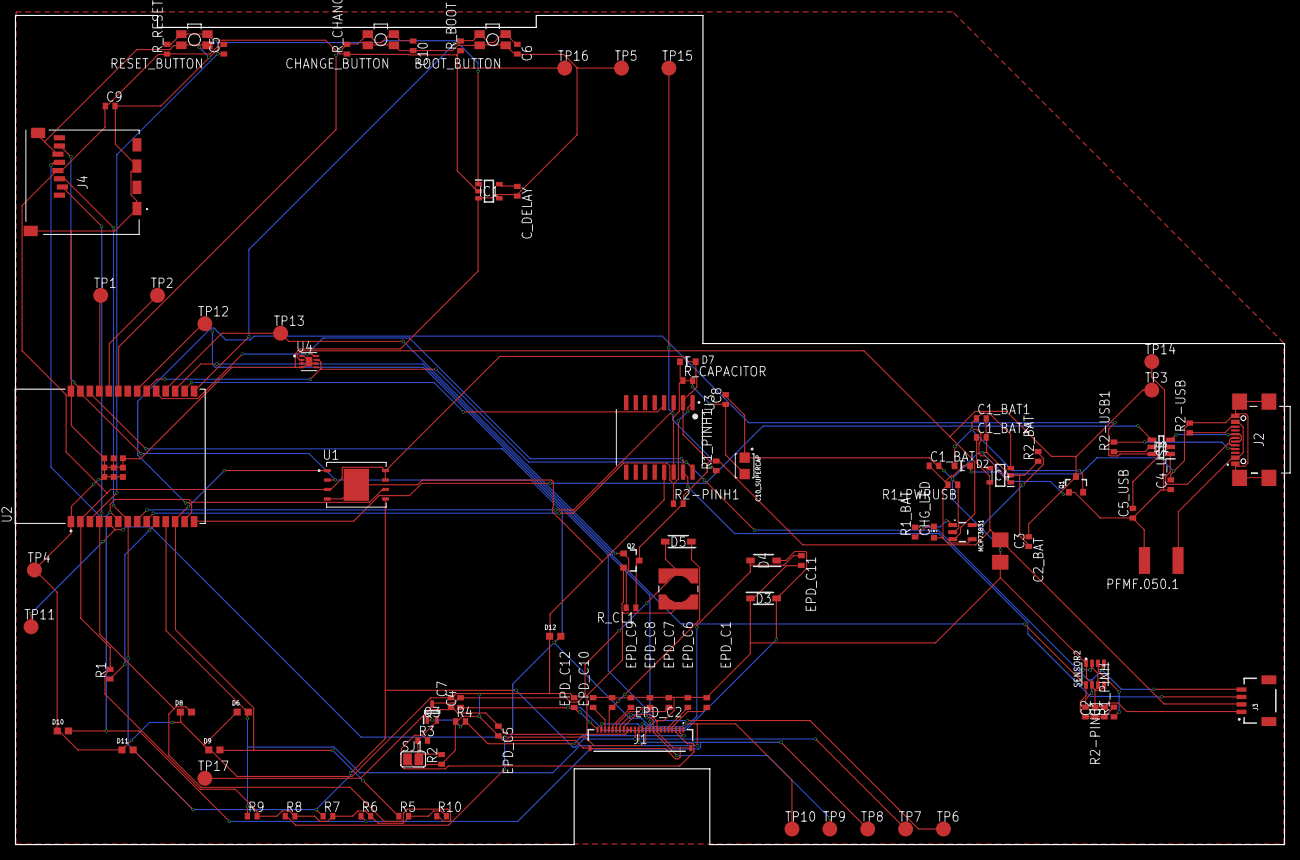
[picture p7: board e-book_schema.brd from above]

Board: 2 copper layers, 170.2 x 111.2 mm, 103 parts (0 on the bottom side), 54 nets.

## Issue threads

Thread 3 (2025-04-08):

[README] Structura README

anamar19, 2025-04-08:
La fisierul [README.md](README.md) ar trebui adaugata o sectiune in care sa mentionezi deciziile luate(de ce ai acceptat cele 2 erori), sa argumentezi de ce ai aranjat componentele in modul in care ai facut-o si sa adaugi randari PCB.

Closed 2025-04-16.

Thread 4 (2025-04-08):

[Mechanical] Amplasarea gresita a display-ului

anamar19, 2025-04-08:
In fisierul [Open Enclosure.f3z](./Mechanical/OpenBook%20Enclosure.f3z) ai pus display-ul pe partea gresita; el trebuie pus in spatele PCB-ului(adica pe partea opusa).

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

Closed 2025-04-16.

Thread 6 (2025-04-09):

[Mechanical] Silkscreen

anamar19, 2025-04-09:
Silkscreen-ul din [Mechanical/OpenBook Enclosure](./Mechanical/OpenBook%20Enclosure.f3z) ar trebui pus mai in clar intrucat se suprapun scrisurile intre ele.

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

Closed 2025-04-16.

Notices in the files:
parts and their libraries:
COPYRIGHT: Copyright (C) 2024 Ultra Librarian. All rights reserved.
